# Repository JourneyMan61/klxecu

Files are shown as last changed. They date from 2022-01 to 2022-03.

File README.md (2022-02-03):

# klxecu

Speeduino based ECM for the fuel injected KLX 250 and 300. Firmware compatible with the Speeduino 0.4.4c. It has only one fuel and ignition channel, but adds a few extra features, namely:

- control of the check engine/temperature warning lights on the dashboard
- control of the secondary throttle plate in the intake (we'll abuse the open loop idle control built in to the speeduino)
- control of the bike's safety switches (tbd, might just use some logic gates. currently a DIP8 socket is available on the board for testing)
- auxiliary "self diag" pin connected to the speeduino processor

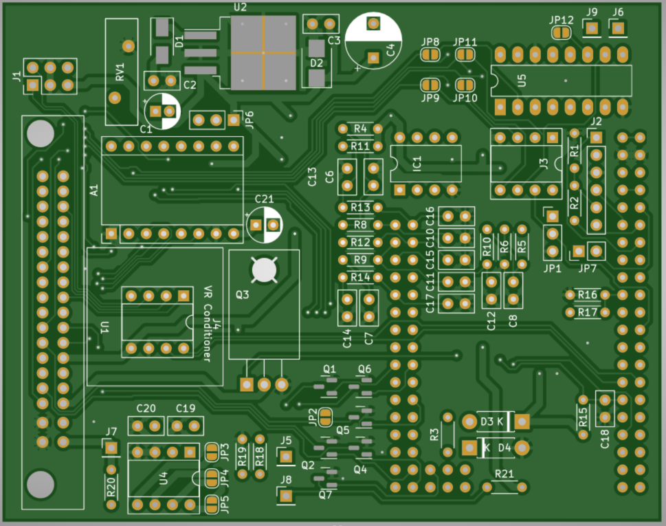
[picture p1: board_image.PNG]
klxecu v1


This project borrows from the following:

- [NO2C Speeduino - https://github.com/turboedge/SpeedyBoards](https://github.com/turboedge/SpeedyBoards) for parts of the board design
- [Speeduino Hardware - https://github.com/speeduino/Hardware](https://github.com/speeduino/Hardware) for the VR conditioner and other bits of the board design
- [Speeduino Firmware - https://github.com/noisymime/speeduino](https://github.com/noisymime/speeduino) for the ECM firmware

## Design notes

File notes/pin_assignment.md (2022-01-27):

# ECM -> Arduino Pin Assingments

| ECM Pin | Function | Schematic Alias | Arduino Pin | ATTiny Pin | Notes |
|---|---|---|---|---|---|
| 1 | Switched 12V Power | +12V | | | Input to onboard PSU |
| 2 | Vehicle Down Sensor | VDOWN | | A2 | |
| 3 | Crankshaft Position + | CKP+ | D19 | | Sensor connected to amp/conditioner, conditioner output<br>connected to D19 |
| 4 | Unconnected | | | | |
| 5 | Throttle Position Sensor | TPS | A2 | | |
| 6 | Intake air pressure sensor | MAP | A3 | | |
| 7 | Oxygen Sensor | O2S | A8 | | |
| 8 | Control Ground | GND | | | Connected to ECM internal ground |
| 9 | Crankshaft Position - | CKP- | D19 | | |
| 10 | External Communication | | | | On the original bike, this is the OEM diagnostic port.<br>It's not useful for speeduino, so it will be left unconnected |
| 11 | Fuel pump relay | FP-RELAY | D45 | | |
| 12 | Starter Lockout Switch / Clutch Switch | CLUTCH-SW | D51 | | Recommended to use for speeduino's launch control input |
| 13 | Sensor power supply | +5V | | | 5 Volts output from ECM's internal power supply |
| 14 | Subthrottle valve actuator B | SUB-B+ | | A5,A6 | B Coil positive lead for subthrottle stepper, connected to the DRV8825 |
| 15 | Subthrottle valve actuator A | SUB-A+ | | A5,A6 | A Coil positive lead for subthrottle stepper, connected to the DRV8825 |
| 16 | Fuel injector | INJ | D8 | | |
| 17 | Oxygen sensor heater | O2S-HEAT | D45 | | Microsquirt docs recommend tying this to the fuel pump.<br>Speeduino doesn't have support for O2 sensor heater control. |
| 18 | Ignition Coil | IGN | D40 | | This is normally a CDI pulse output, for v1 of the board it<br>may be a logic level output for a smart coil |
| 19 | Power supply from battery | +BATT | | | Always-on power directly from the vehicle's battery |
| 20 | Neutral Switch | NEUTRAL | | A3 | Used by the attiny to halt the main processor if we're in gear<br>and the kickstand is down |
| 21 | Check engine light | MIL | D32 | D10 | Speeduino supports programmable outputs, so we could flash the<br>lamp when engine protection is triggered or something. The speeduino will tell the<br>ATTiny something is wrong, then the ATTiny will activate the lamp. The ATTiny can also activate the lamp if the safety switch is triggered. |
| 22 | Water temperature sensor | CLT | A1 | | |
| 23 | Self diagnosis terminal | SELF-DIAG | D53? | | Will be tied to a generic digital input |
| 24 | Sensor Ground | GND | | | Ground for pressure sensors, etc. |
| 25 | Intake air temperature sensor | IAT | A0 | | |
| 26 | Speed Sensor | VSS | D20 | | Speeduino supports gear detection, maybe we can do something<br>useful with that information |
| 27 | Subthrottle sensor | SUB-TPS | | A1 | Used so the ATTiny can tell when the secondary throttle valves<br>are fully open |
| 28 | Coolant temperature warning light | TEMP-WARN | tbd | | Controlled by the speeduino's programmable outputs, can trigger<br>at a customizable temperature |
| 29 | Side stand switch | SIDE-SW | | A4 | Used by the attiny to halt the main processor if we're in gear and<br>the kickstand is down |
| 30 | Air switching valve | n/a | | | Injects air into the exhaust stream, will not be supported in v1 |
| 31 | Subthrottle valve actuator A | SUB-A- | | A5,A6 | A coil negative lead for the subthrottle stepper, connected to the DRV8825 |
| 32 | Subthrottle valve actuator B | SUB-B- | | A5,A6 | B coil negative lead for the subthrottle stepper, connected to the DRV8825 |
| 33 | Radiator Fan relay | FAN-RELAY | D47 | | |
| 34 | Engine stop switch | KILL-SW | | | This switch already provides power to the fuel injectors and fuel pump,<br>it's probably fine to leave this unconnected. or connect to the ATTiny so<br>it can shut the secondary throttles if the killswitch is enabled? |
| 35 | Ground for ECM | GND | | | |
| 36 | Ground for ECM | GND | | | 

# Auxiliary Pins
| Board Pin | Function | Schematic Alias | Arduino Pin | ATTiny Pin | Notes |
|---|---|---|---|---|---|
| J?1 | Camshaft Position Sensor + | CAM+ | D18 | | Auxiliary camshaft position sensor input, if you want to run sequential ignition... the VR conditioner has 2 channels so why not? |
| J?2 | Camshaft Position Sensor - | CAM- | D18 | | Auxiliary camshaft position sensor input, if you want to run sequential ignition... the VR conditioner has 2 channels so why not? |
| J? | Tacho output | TACH | D49 | | Tach output if needed, pads can be left blank

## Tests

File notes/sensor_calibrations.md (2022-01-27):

# Sensor Calibrations

### Throttle Position Sensor
- Input voltage spec: 5V
- Output at closed throttle: 0.58-0.62 V
- Output at WOT: 3.7-3.9V

### Crankshaft Position Sensor
- Type: Variable Reluctance
- Trigger pattern: 18-1*
- Trigger angle: ?
- Voltage peak: 3.2V

### MAP Sensor
- Pressure at 0V: ?
- Pressure at 5V: ?
- Sensor spec is 2.87-2.93V at 101.35 kPa, will need to calibrate

### O2 Sensor
- Type: Narrowband
- Rich: 0.8V and up
- Lean: 0.24V and below

### Coolant Temperature Sensor
- -20c: 18.80k +/- 2.37k
- 0c: 6.544k
- 40c: 1.136k +/- 0.095k
- 100c: 0.1553k +/- 0.0070k
- Bias resistor: TBD
- Spec voltage: 2.8-2.97V at 20c (probably won't apply for us because the bias reistor is different)

### Intake air temperature sensor
- 0c: 6k +/- 0.6k
- 80c: 0.34k +/- 0.05k
- Spec voltage at 20c is 2.375 +/- 0.125V, which works out to a theoretical resistance of 2.5k. Will need to experimentally test though.

### Subthrottle Position sensor
- Input voltage spec: 5V
- Output at closed throttle: 0.48-0.52V
- Output at WOT: 3.60-3.80V

### Speed Sensor
- Type: Hall effect
- Spec: 0-5v output
- 8 pulses per rotation

### Kickstand
- Up: Logic low (ground)
- Down: Logic high (pullup to 5V?)**

### Neutral switch
- Neutral: low
- In gear: hign (pullup to 5V?)**

### Clutch Switch
- Pulled in: low
- let out: high (pulled up? who knows. let's see)

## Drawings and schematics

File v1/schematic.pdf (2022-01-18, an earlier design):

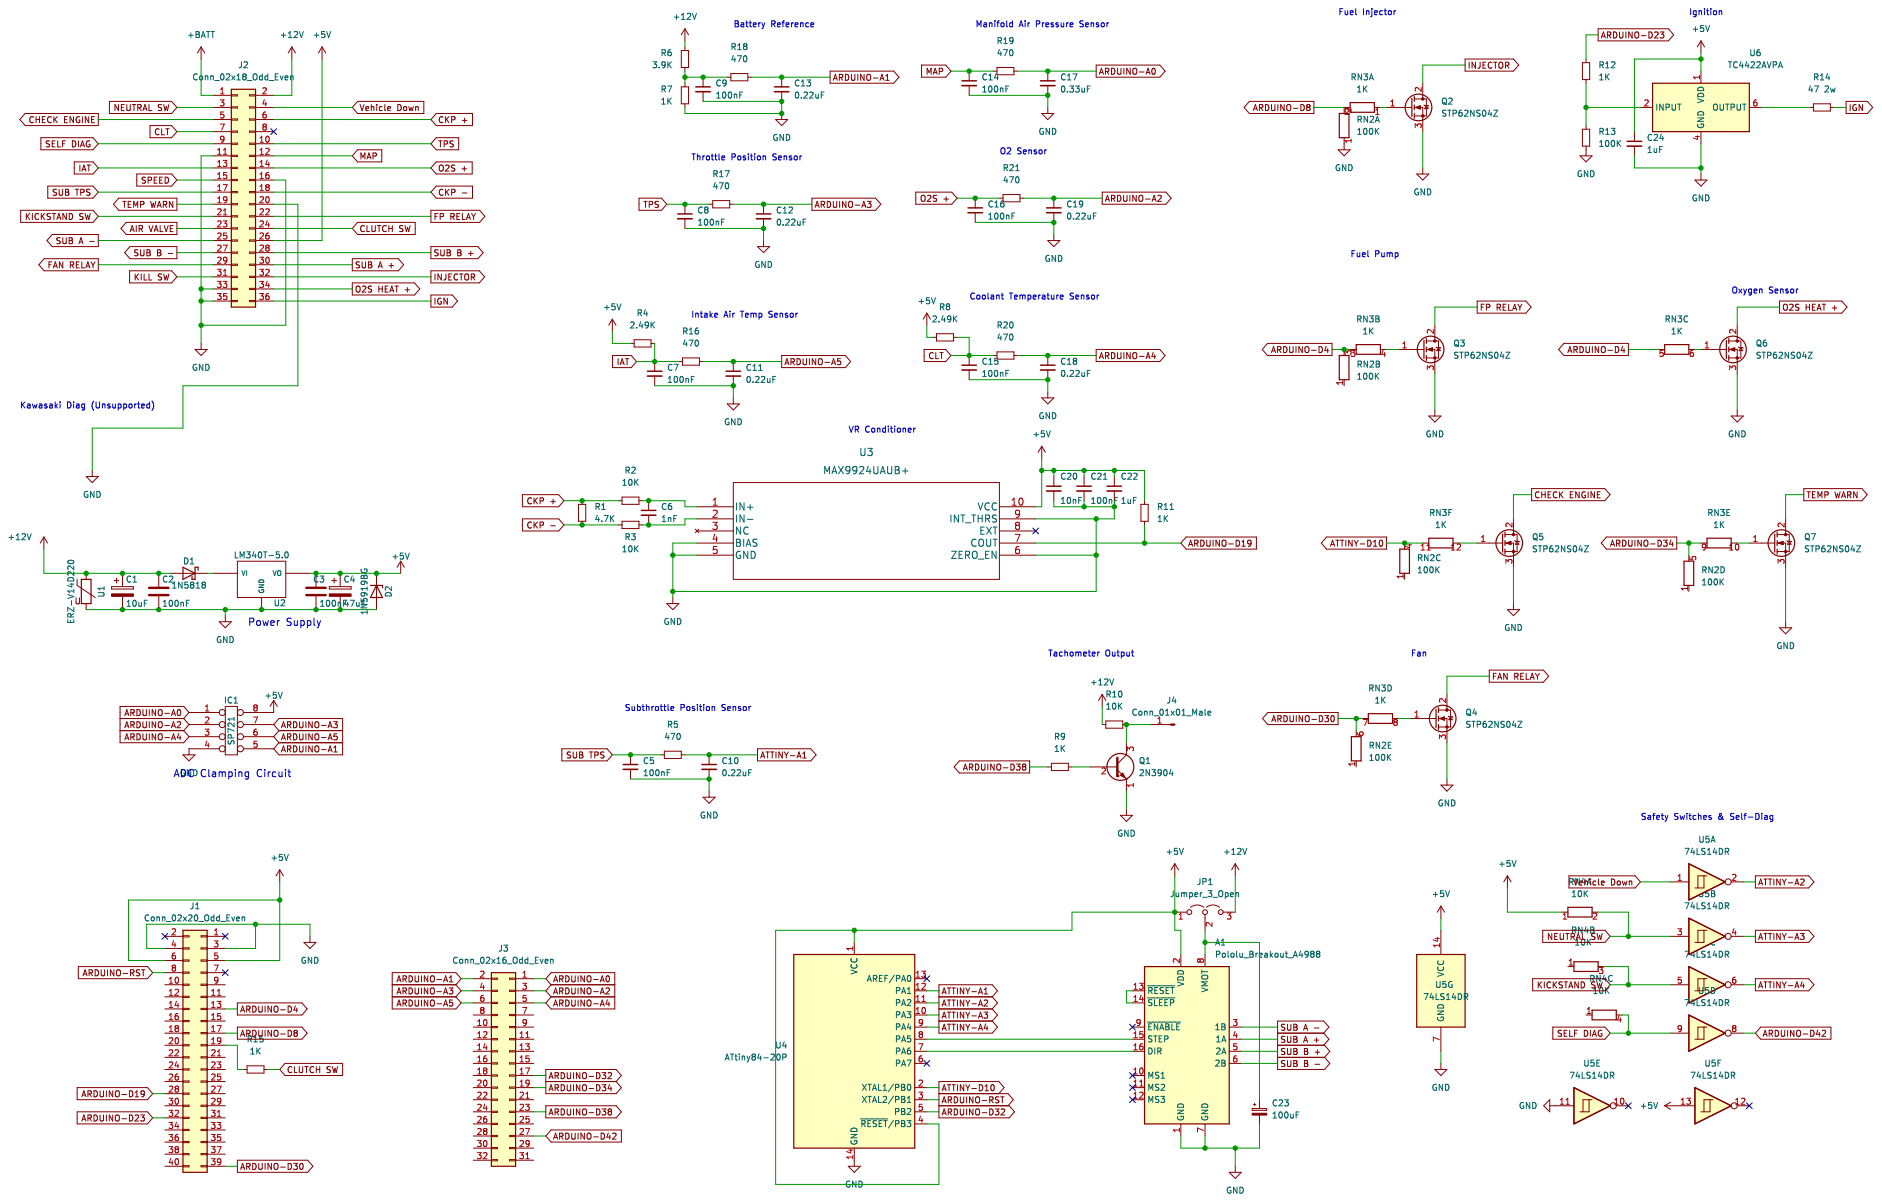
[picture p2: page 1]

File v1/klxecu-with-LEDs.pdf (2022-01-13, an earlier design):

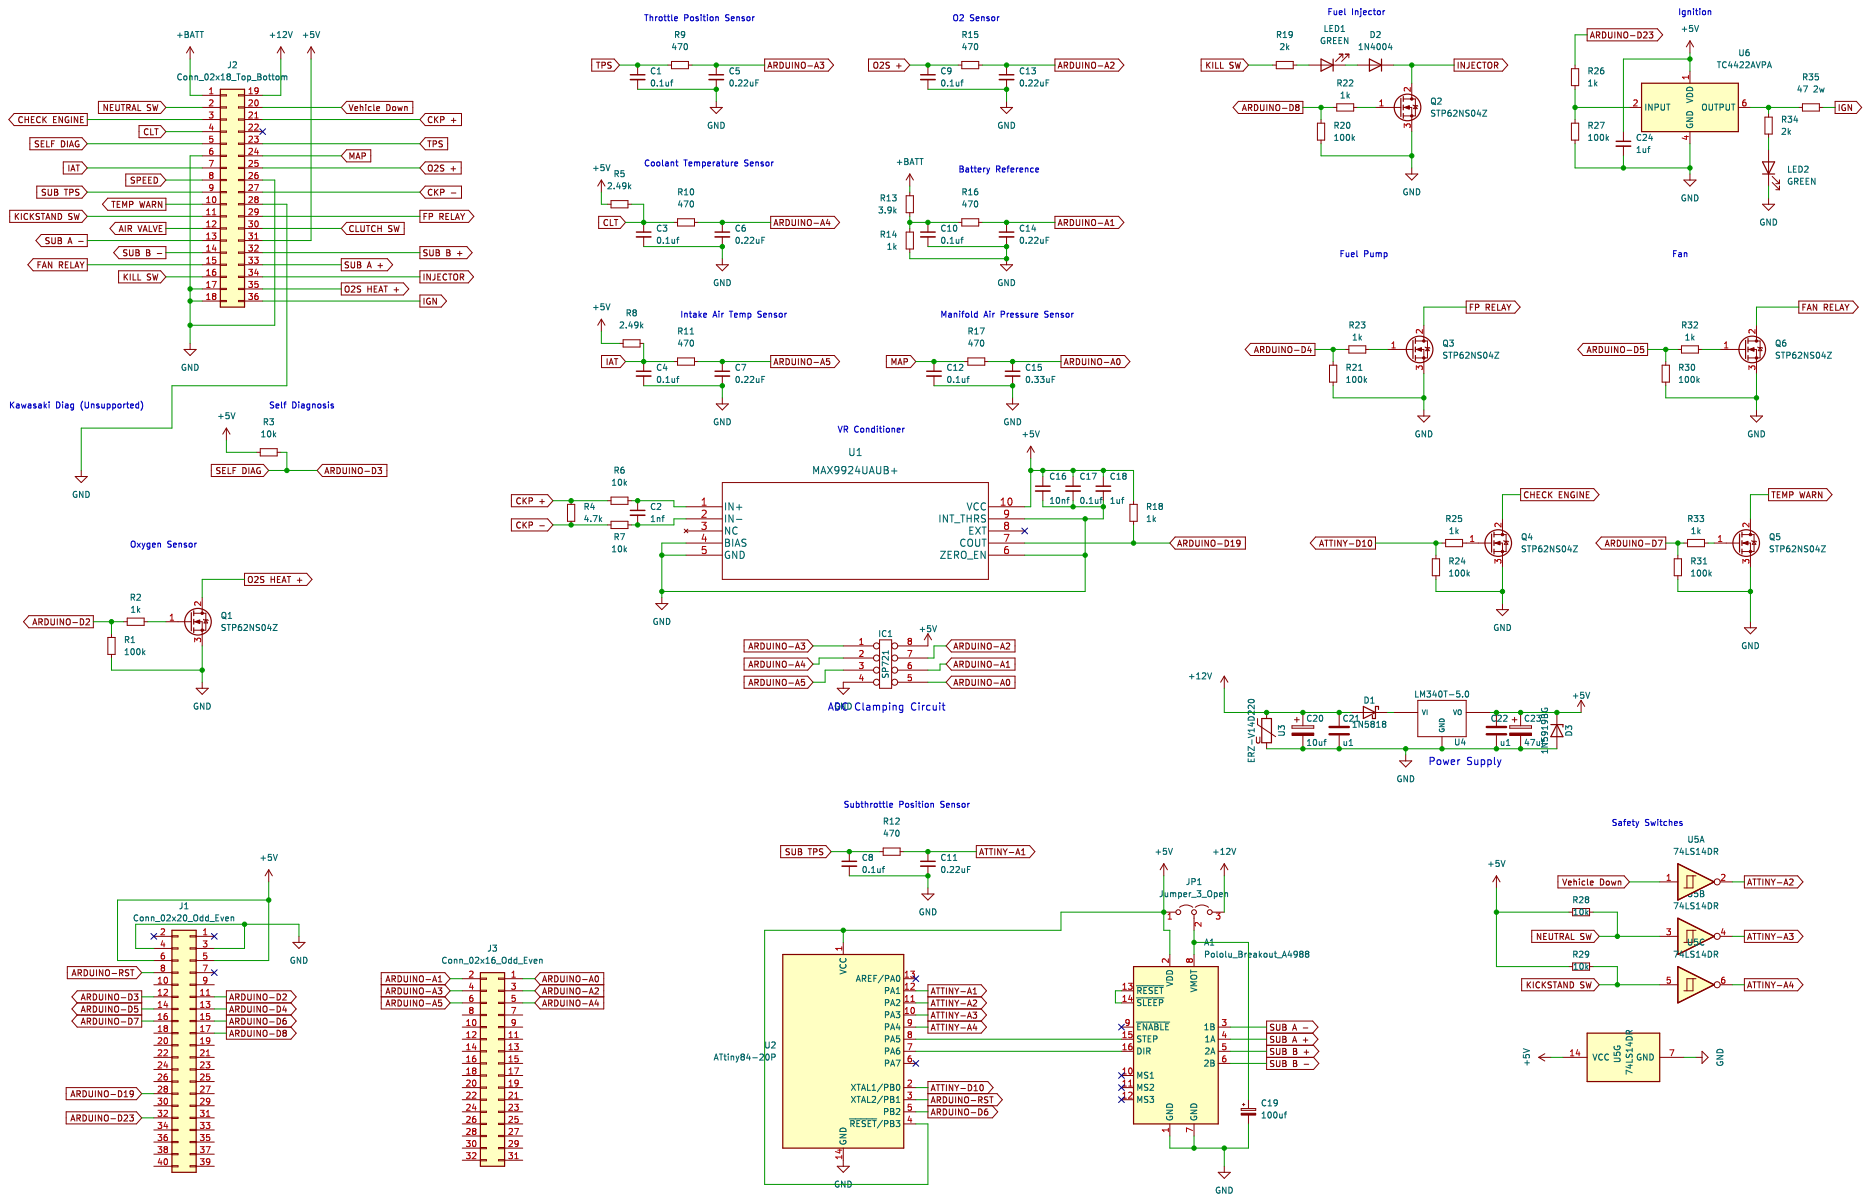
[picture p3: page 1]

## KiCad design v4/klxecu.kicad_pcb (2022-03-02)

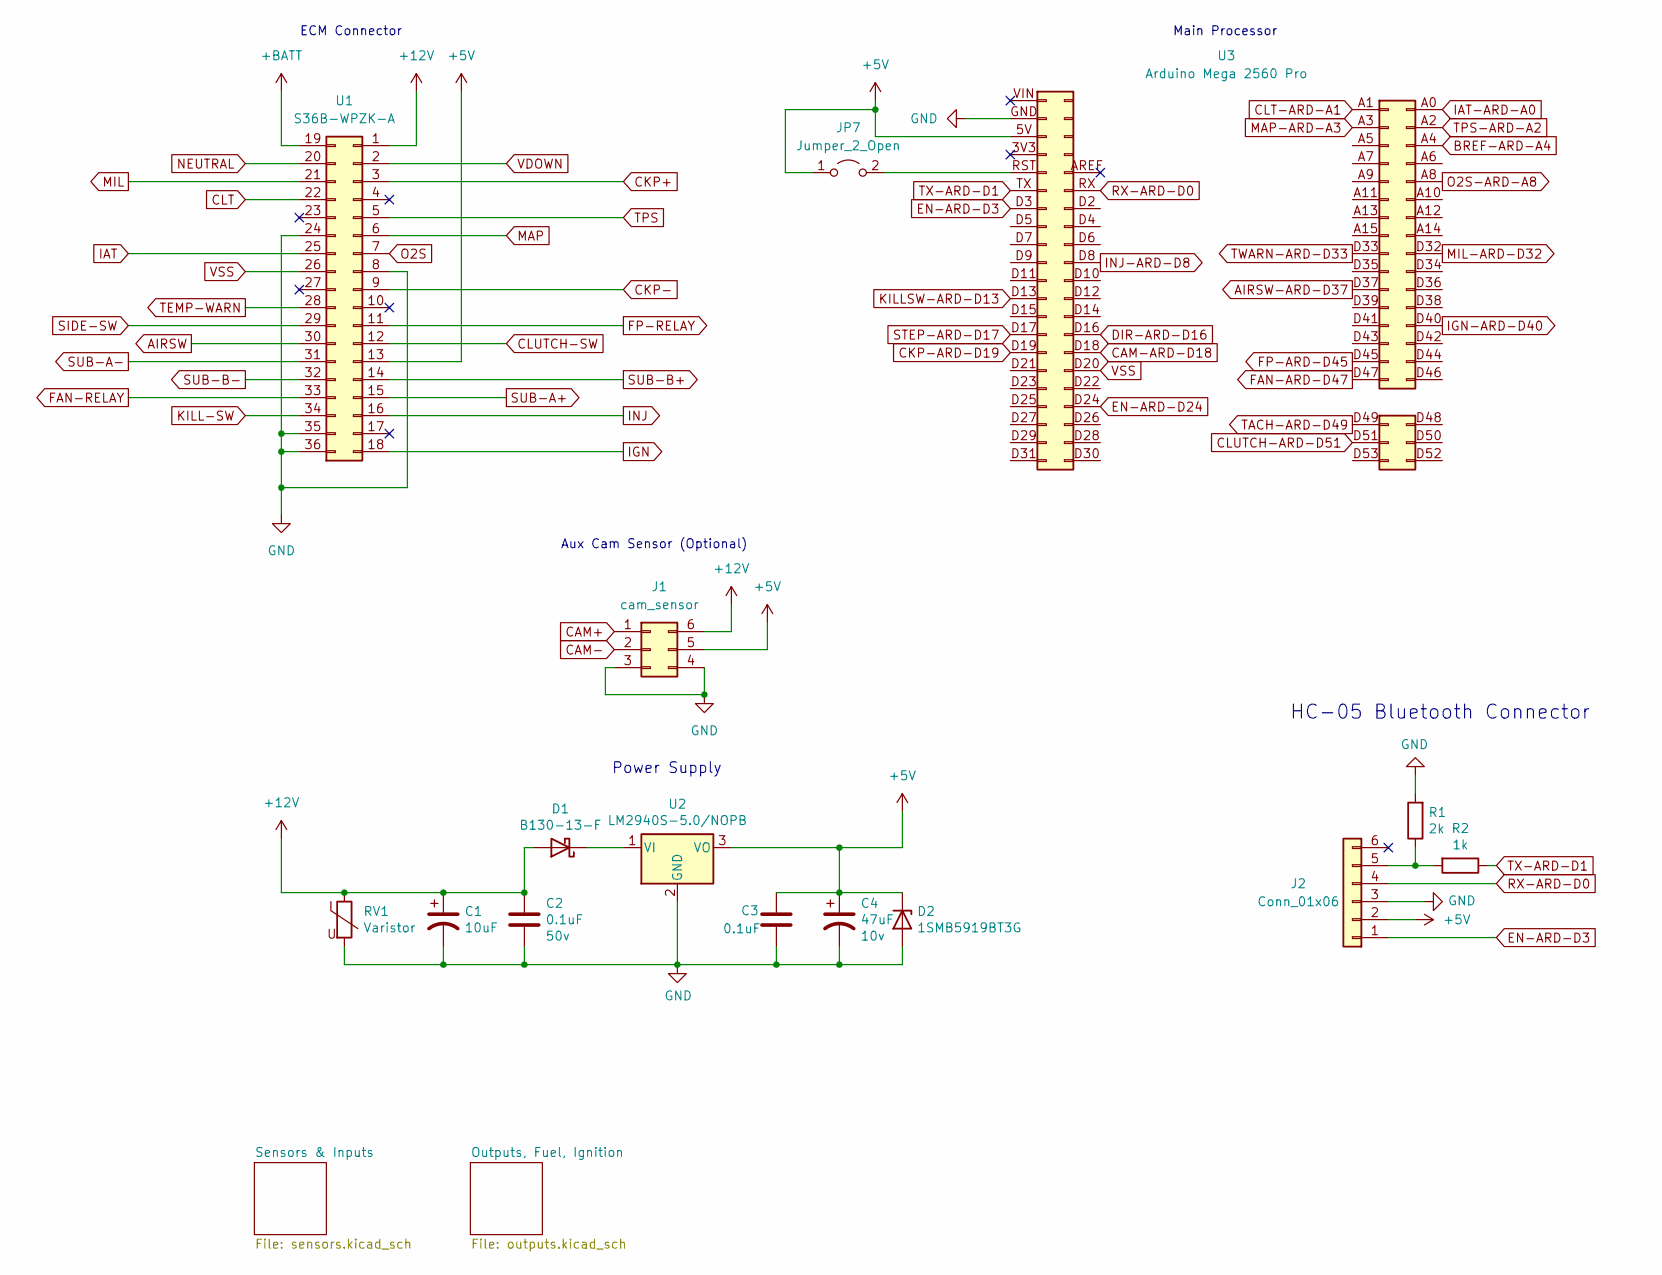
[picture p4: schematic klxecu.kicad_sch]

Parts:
C1: 10uF; CP_Radial_D5.0mm_P2.00mm; Voltage 35v; Manufacturer_Part_Number T491D106K050AT; Digikey Part Number 399-8361-1-ND
C2: 0.1uF; C_Disc_D5.0mm_W2.5mm_P2.50mm; Voltage 50v; Manufacturer_Part_Number CC0805KRX7R9BB104; Digikey Part Number 311-1140-1-ND
C3: 0.1uF; C_Disc_D5.0mm_W2.5mm_P2.50mm; Manufacturer_Part_Number CC0805KRX7R9BB104; Digikey Part Number 311-1140-1-ND
C4: 47uF; CP_Radial_D8.0mm_P5.00mm; Voltage 10v; Manufacturer_Part_Number TAJB476K006RNJ; Digikey Part Number 478-1692-1-ND
D1: B130-13-F; D_SMA; Manufacturer_Part_Number B130-13-F; Digikey Part Number B130-FDICT-ND
D2: 1SMB5919BT3G; D_SMB; Manufacturer_Part_Number 1SMB5919BT3G; Digikey Part Number 1SMB5919BT3GOSCT-ND
J1: cam_sensor; PinHeader_2x03_P2.54mm_Vertical
J2: Conn_01x06; PinHeader_1x06_P2.54mm_Vertical
JP7: Jumper_2_Open; PinHeader_1x02_P2.54mm_Vertical
R1: 2k; R_Axial_DIN0204_L3.6mm_D1.6mm_P5.08mm_Horizontal; Manufacturer_Part_Number RC0805FR-072KL; Digikey Part Number 311-2.00KCRCT-ND
R2: 1k; R_Axial_DIN0204_L3.6mm_D1.6mm_P5.08mm_Horizontal; Manufacturer_Part_Number RC0805FR-071KL; Digikey Part Number 311-1.00KCRCT-ND
RV1: Varistor; RV_Disc_D15.5mm_W4.7mm_P7.5mm; Manufacturer_Part_Number MOV-14D220K; Digikey Part Number MOV-14D220K-ND
U1: S36B-WPZK-A
U2: LM2940S-5.0/NOPB; TO-263-3_TabPin2; Manufacturer_Part_Number LM2940S-5.0/NOPB; Digikey Part Number LM2940S-5.0/NOPB-ND
U3: Arduino Mega 2560 Pro; mega_2560_pro

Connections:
+5V: C3.1, C4.1, D2.1 (K), J1.5, J2.2, JP7.1 (A), U1.13, U2.3 (VO), U3.5V; also elsewhere on the board
+12V: C1.1, C2.1, D1.2 (A), J1.6, RV1.1, U1.1; also elsewhere on the board
+BATT: U1.19
AIRSW: U1.30; also elsewhere on the board
AIRSW-ARD-D37: U3.D37; also elsewhere on the board
BREF-ARD-A4: U3.A4; also elsewhere on the board
CAM+: J1.1; also elsewhere on the board
CAM-: J1.2; also elsewhere on the board
CAM-ARD-D18: U3.D18; also elsewhere on the board
CKP+: U1.3; also elsewhere on the board
CKP-: U1.9; also elsewhere on the board
CKP-ARD-D19: U3.D19; also elsewhere on the board
CLT: U1.22; also elsewhere on the board
CLT-ARD-A1: U3.A1; also elsewhere on the board
CLUTCH-ARD-D51: U3.D51; also elsewhere on the board
CLUTCH-SW: U1.12; also elsewhere on the board
DIR-ARD-D16: U3.D16; also elsewhere on the board
EN-ARD-D3: J2.1, U3.D3
EN-ARD-D24: U3.D24; also elsewhere on the board
FAN-ARD-D47: U3.D47; also elsewhere on the board
FAN-RELAY: U1.33; also elsewhere on the board
FP-ARD-D45: U3.D45; also elsewhere on the board
FP-RELAY: U1.11; also elsewhere on the board
GND: C1.2, C2.2, C3.2, C4.2, D2.2 (A), J1.3, J1.4, J2.3, R1.2, RV1.2, U1.8, U1.24, U1.35, U1.36, U2.2 (GND), U3.GND; also elsewhere on the board
IAT: U1.25; also elsewhere on the board
IAT-ARD-A0: U3.A0; also elsewhere on the board
IGN: U1.18; also elsewhere on the board
IGN-ARD-D40: U3.D40; also elsewhere on the board
INJ: U1.16; also elsewhere on the board
INJ-ARD-D8: U3.D8; also elsewhere on the board
KILL-SW: U1.34; also elsewhere on the board
KILLSW-ARD-D13: U3.D13; also elsewhere on the board
MAP: U1.6; also elsewhere on the board
MAP-ARD-A3: U3.A3; also elsewhere on the board
MIL: U1.21; also elsewhere on the board
MIL-ARD-D32: U3.D32; also elsewhere on the board
NEUTRAL: U1.20; also elsewhere on the board
unnamed: D1.1 (K), U2.1 (VI)
unnamed: J2.5, R1.1, R2.2
unnamed: JP7.2 (B), U3.RST
O2S: U1.7; also elsewhere on the board
O2S-ARD-A8: U3.A8; also elsewhere on the board
RX-ARD-D0: J2.4, U3.RX
SIDE-SW: U1.29; also elsewhere on the board
STEP-ARD-D17: U3.D17; also elsewhere on the board
SUB-A+: U1.15; also elsewhere on the board
SUB-A-: U1.31; also elsewhere on the board
SUB-B+: U1.14; also elsewhere on the board
SUB-B-: U1.32; also elsewhere on the board
TACH-ARD-D49: U3.D49; also elsewhere on the board
TEMP-WARN: U1.28; also elsewhere on the board
TPS: U1.5; also elsewhere on the board
TPS-ARD-A2: U3.A2; also elsewhere on the board
TWARN-ARD-D33: U3.D33; also elsewhere on the board
TX-ARD-D1: R2.1, U3.TX
VDOWN: U1.2; also elsewhere on the board
VSS: U1.26, U3.D20; also elsewhere on the board

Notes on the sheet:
Aux Cam Sensor (Optional)
HC-05 Bluetooth Connector
ECM Connector
Main Processor
Power Supply

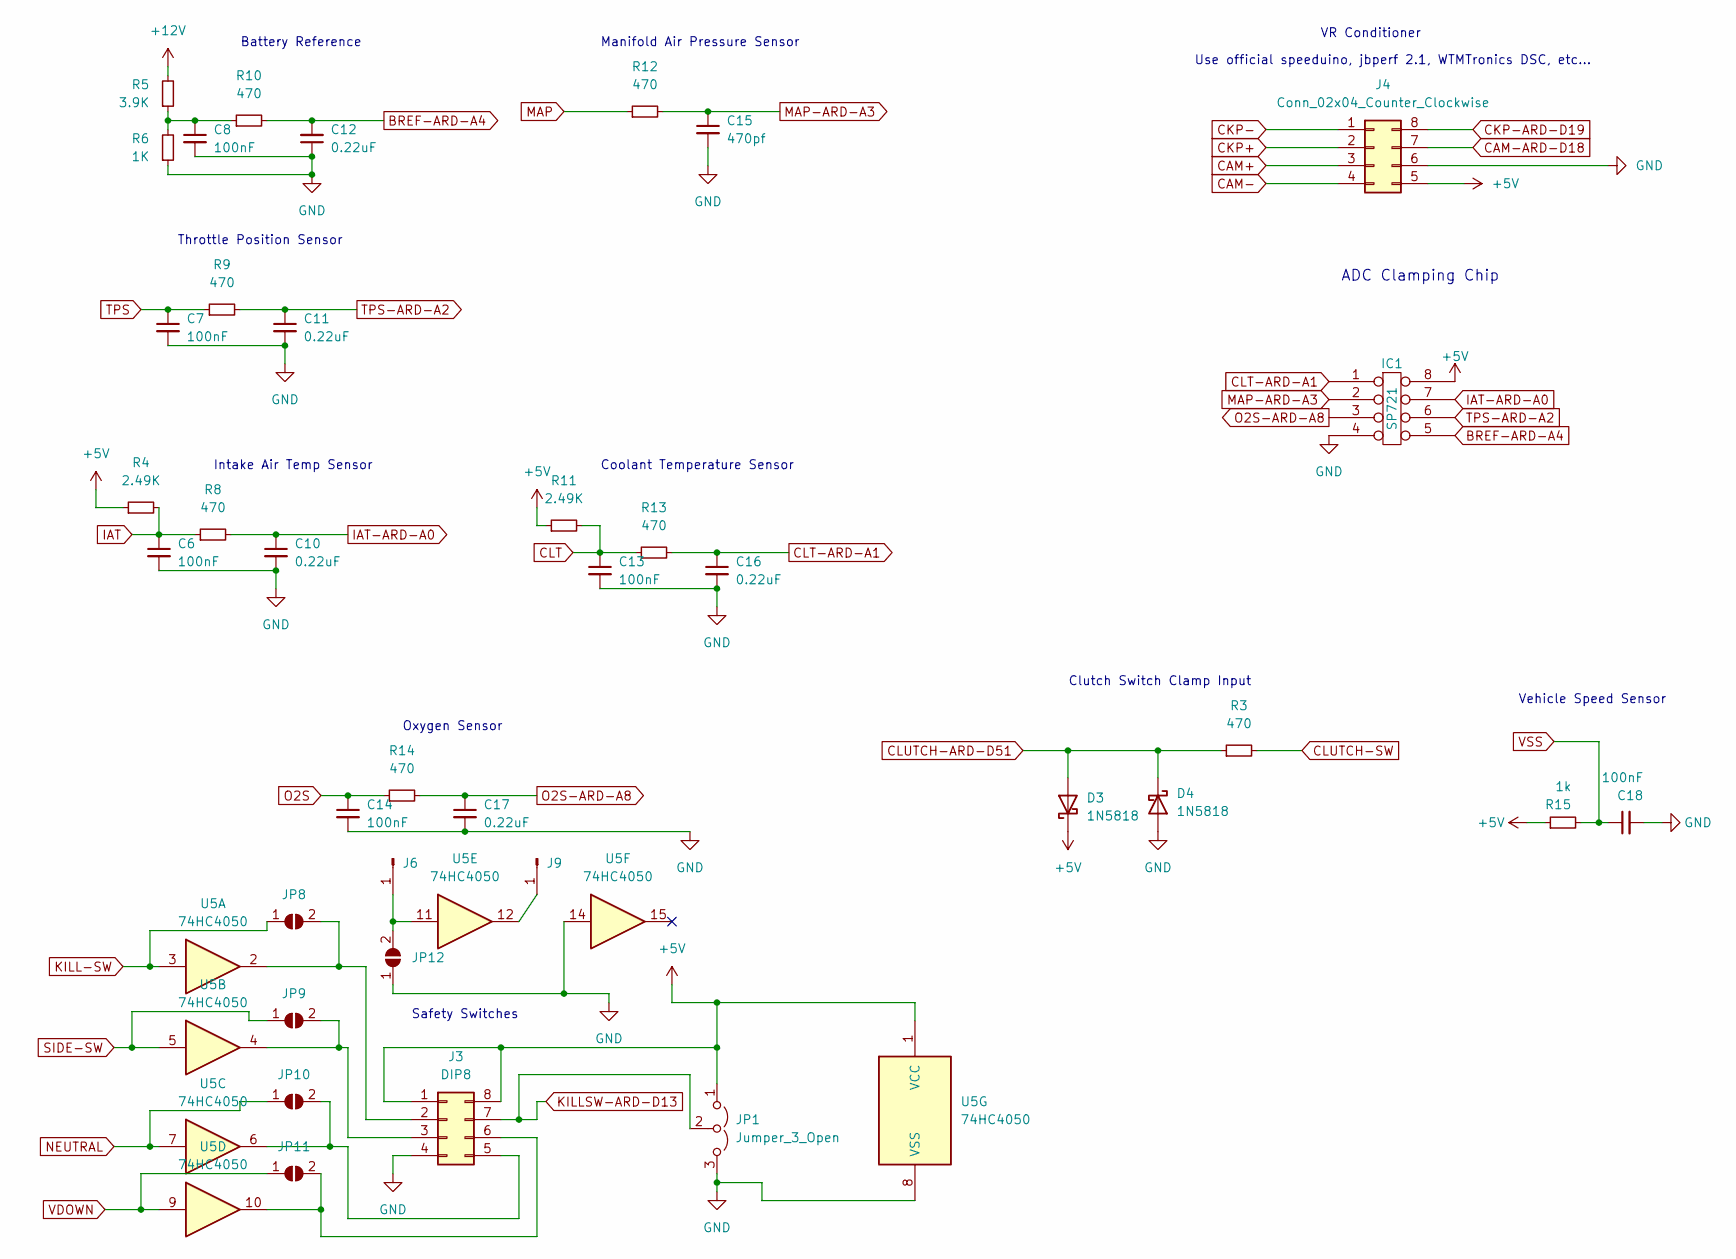
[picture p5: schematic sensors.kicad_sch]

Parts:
C6, C7, C8, C13, C14: 100nF; C_Disc_D5.0mm_W2.5mm_P2.50mm
C10, C11, C12, C16, C17: 0.22uF; C_Disc_D5.0mm_W2.5mm_P2.50mm
C15: 470pf; C_Disc_D5.0mm_W2.5mm_P2.50mm
C18: 100nF; C_Disc_D5.0mm_W2.5mm_P2.50mm; Manufacturer_Part_Number CC0805KRX7R9BB104; Digikey 311-1140-1-ND
D3, D4: 1N5818; D_DO-41_SOD81_P7.62mm_Horizontal
IC1: SP721; DIP-8_W7.62mm
J3: DIP8; DIP-8_W7.62mm_Socket
J4: Conn_02x04_Counter_Clockwise; vr_conditioner
J6, J9: Conn_01x01_Male; PinHeader_1x01_P2.54mm_Vertical
JP1: Jumper_3_Open; PinHeader_1x03_P2.54mm_Vertical
JP8, JP9, JP10, JP11, JP12: SolderJumper_2_Open; SolderJumper-2_P1.3mm_Open_RoundedPad1.0x1.5mm
R3, R8, R9, R10, R12, R13, R14: 470; R_Axial_DIN0204_L3.6mm_D1.6mm_P5.08mm_Horizontal
R4, R11: 2.49K; R_Axial_DIN0204_L3.6mm_D1.6mm_P5.08mm_Horizontal
R5: 3.9K; R_Axial_DIN0204_L3.6mm_D1.6mm_P5.08mm_Horizontal
R6: 1K; R_Axial_DIN0204_L3.6mm_D1.6mm_P5.08mm_Horizontal
R15: 1k; R_Axial_DIN0204_L3.6mm_D1.6mm_P5.08mm_Horizontal
U5: 74HC4050; DIP-16_W7.62mm_LongPads

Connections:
+5V: D3.1 (K), IC1.8, J3.1, J3.8, J4.5, JP1.1 (A), R4.1, R11.1, R15.1, U5.1 (VCC); also elsewhere on the board
+12V: R5.2; also elsewhere on the board
BREF-ARD-A4: C12.2, IC1.5, R10.2; also elsewhere on the board
CAM+: J4.3; also elsewhere on the board
CAM-: J4.4; also elsewhere on the board
CAM-ARD-D18: J4.7; also elsewhere on the board
CKP+: J4.2; also elsewhere on the board
CKP-: J4.1; also elsewhere on the board
CKP-ARD-D19: J4.8; also elsewhere on the board
CLT: C13.1, R11.2, R13.1; also elsewhere on the board
CLT-ARD-A1: C16.1, IC1.1, R13.2; also elsewhere on the board
CLUTCH-ARD-D51: D3.2 (A), D4.1 (K), R3.1; also elsewhere on the board
CLUTCH-SW: R3.2; also elsewhere on the board
GND: C6.2, C7.2, C8.2, C10.2, C11.2, C12.1, C13.2, C14.2, C15.2, C16.2, C17.2, C18.2, D4.2 (A), IC1.4, J3.4, J4.6, JP1.3 (B), JP12.1 (A), R6.1, U5.8 (VSS), U5.14; also elsewhere on the board
IAT: C6.1, R4.2, R8.1; also elsewhere on the board
IAT-ARD-A0: C10.1, IC1.7, R8.2; also elsewhere on the board
KILL-SW: JP8.1 (A), U5.3; also elsewhere on the board
KILLSW-ARD-D13: J3.7, JP1.2 (C); also elsewhere on the board
MAP: R12.1; also elsewhere on the board
MAP-ARD-A3: C15.1, IC1.2, R12.2; also elsewhere on the board
NEUTRAL: JP10.1 (A), U5.7; also elsewhere on the board
unnamed: C8.1, R5.1, R6.2, R10.1
unnamed: J3.2, JP8.2 (B), U5.2
unnamed: J3.3, JP9.2 (B), U5.4
unnamed: J3.5, JP10.2 (B), U5.6
unnamed: J3.6, JP11.2 (B), U5.10
unnamed: J6.1, JP12.2 (B), U5.11
unnamed: J9.1, U5.12
O2S: C14.1, R14.1; also elsewhere on the board
O2S-ARD-A8: C17.1, IC1.3, R14.2; also elsewhere on the board
SIDE-SW: JP9.1 (A), U5.5; also elsewhere on the board
TPS: C7.1, R9.1; also elsewhere on the board
TPS-ARD-A2: C11.1, IC1.6, R9.2; also elsewhere on the board
VDOWN: JP11.1 (A), U5.9; also elsewhere on the board
VSS: C18.1, R15.2; also elsewhere on the board

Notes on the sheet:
Throttle Position Sensor
Coolant Temperature Sensor
Clutch Switch Clamp Input
Intake Air Temp Sensor
Manifold Air Pressure Sensor
Safety Switches
VR Conditioner
Vehicle Speed Sensor
Battery Reference
Use official speeduino, jbperf 2.1, WTMTronics DSC, etc...
ADC Clamping Chip
Oxygen Sensor

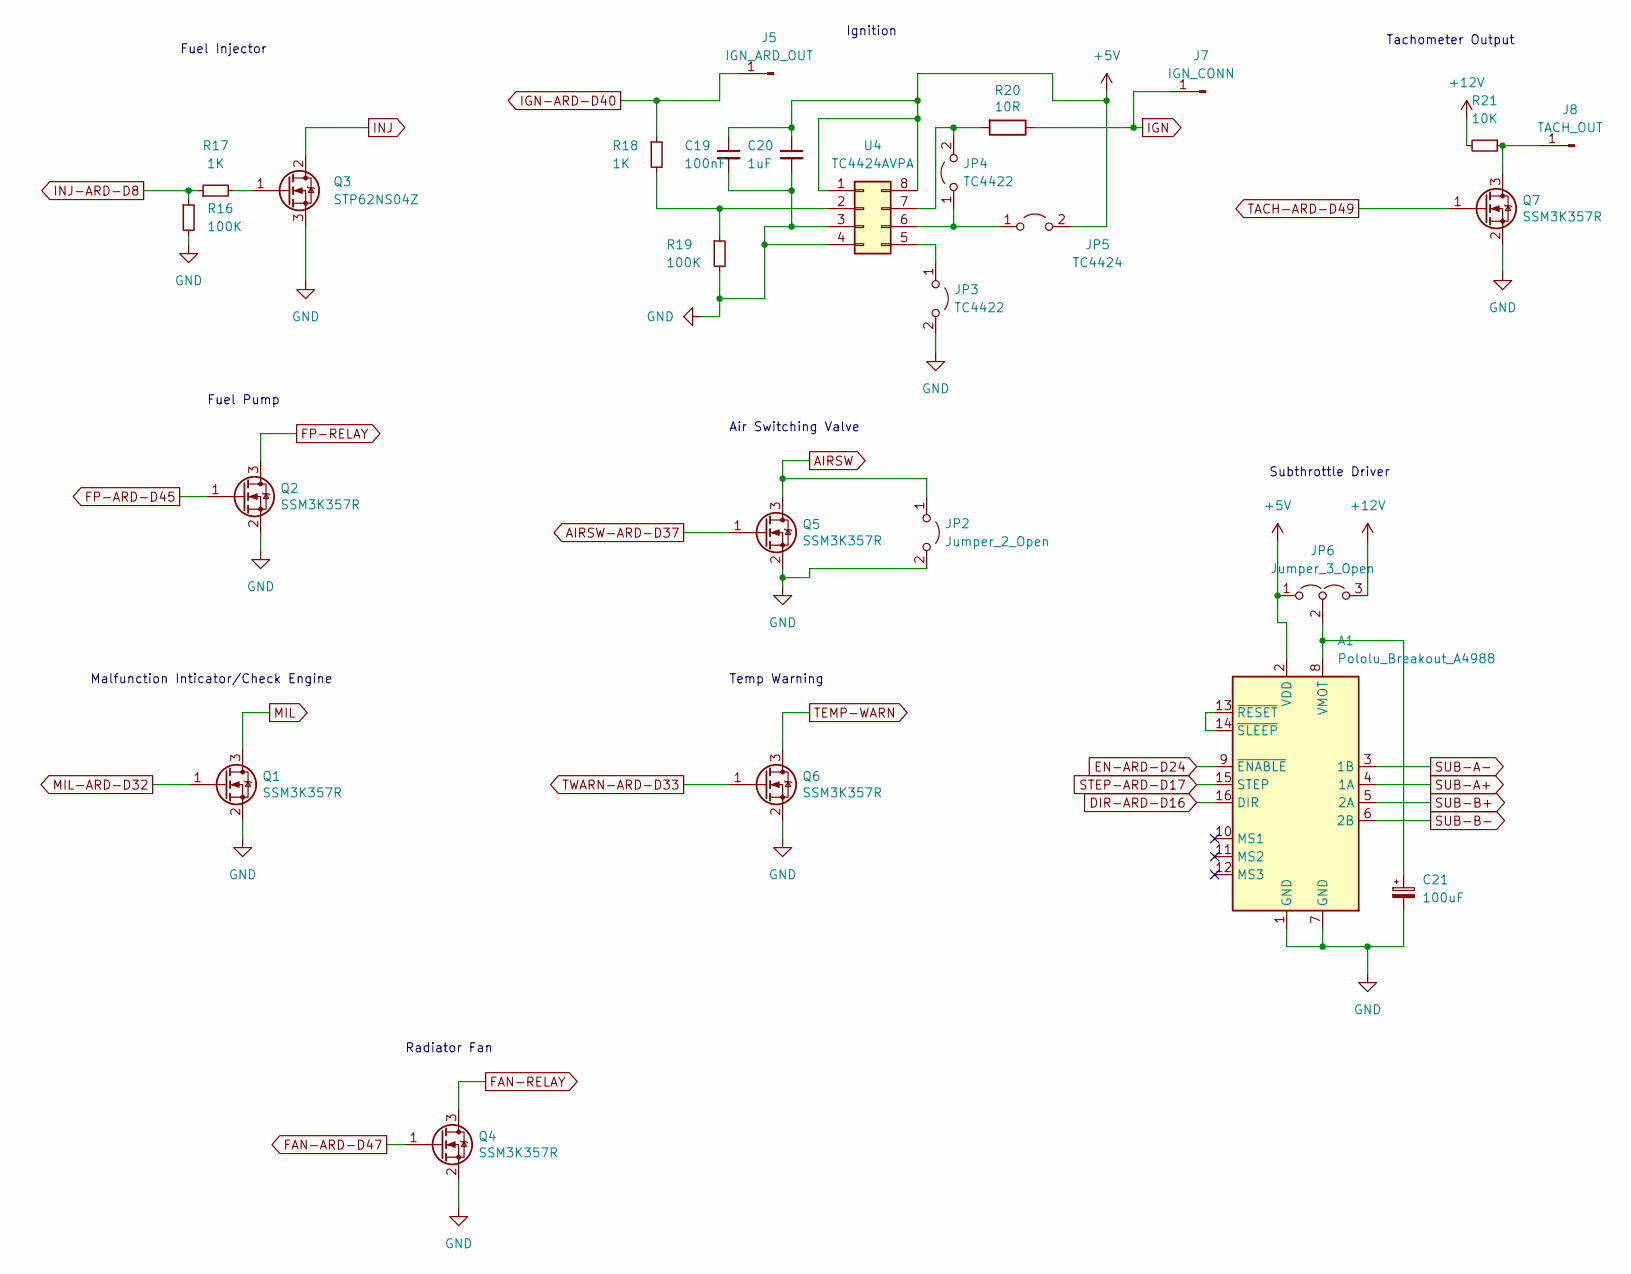
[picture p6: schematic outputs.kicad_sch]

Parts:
A1: Pololu_Breakout_A4988; Pololu_Breakout-16_15.2x20.3mm
C19: 100nF; C_Disc_D5.0mm_W2.5mm_P2.50mm
C20: 1uF; C_Disc_D5.0mm_W2.5mm_P2.50mm
C21: 100uF; CP_Radial_D5.0mm_P2.50mm
J5: IGN_ARD_OUT; PinHeader_1x01_P2.54mm_Vertical
J7: IGN_CONN; PinHeader_1x01_P2.54mm_Vertical
J8: TACH_OUT; PinHeader_1x01_P2.54mm_Vertical
JP2: Jumper_2_Open; SolderJumper-2_P1.3mm_Open_RoundedPad1.0x1.5mm
JP3, JP4: TC4422; SolderJumper-2_P1.3mm_Open_RoundedPad1.0x1.5mm
JP5: TC4424; SolderJumper-2_P1.3mm_Open_RoundedPad1.0x1.5mm
JP6: Jumper_3_Open; PinHeader_1x03_P2.54mm_Vertical
Q1, Q2, Q4, Q5, Q6, Q7: SSM3K357R; SOT-23; Manufacturer_Part_Number SSM3K357R; Digikey Part Number SSM3K357RLFCT-ND
Q3: STP62NS04Z; TO-220-3_Horizontal_TabDown
R16, R19: 100K; R_Axial_DIN0204_L3.6mm_D1.6mm_P5.08mm_Horizontal
R17, R18: 1K; R_Axial_DIN0204_L3.6mm_D1.6mm_P5.08mm_Horizontal
R20: 10R; R_Axial_DIN0204_L3.6mm_D1.6mm_P5.08mm_Horizontal; Manufacturer_Part_Number RC0805FR-0710RL; Digikey Part Number 311-10.0CRCT-ND
R21: 10K; R_Axial_DIN0204_L3.6mm_D1.6mm_P5.08mm_Horizontal
U4: TC4424AVPA; DIP-8_W7.62mm_Socket

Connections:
+5V: A1.2 (VDD), C19.1, C20.1, JP5.2 (B), JP6.1 (A), U4.1, U4.8; also elsewhere on the board
+12V: JP6.3 (B), R21.2; also elsewhere on the board
AIRSW: JP2.1 (A), Q5.3 (D); also elsewhere on the board
AIRSW-ARD-D37: Q5.1 (G); also elsewhere on the board
DIR-ARD-D16: A1.16 (DIR); also elsewhere on the board
EN-ARD-D24: A1.9 (~ENABLE); also elsewhere on the board
FAN-ARD-D47: Q4.1 (G); also elsewhere on the board
FAN-RELAY: Q4.3 (D); also elsewhere on the board
FP-ARD-D45: Q2.1 (G); also elsewhere on the board
FP-RELAY: Q2.3 (D); also elsewhere on the board
GND: A1.1 (GND), A1.7 (GND), C19.2, C20.2, C21.2, JP2.2 (B), JP3.2 (B), Q1.2 (S), Q2.2 (S), Q3.3 (S), Q4.2 (S), Q5.2 (S), Q6.2 (S), Q7.2 (S), R16.2, R19.2, U4.3, U4.4; also elsewhere on the board
IGN: J7.1, R20.1; also elsewhere on the board
IGN-ARD-D40: J5.1, R18.1; also elsewhere on the board
INJ: Q3.2 (D); also elsewhere on the board
INJ-ARD-D8: R16.1, R17.1; also elsewhere on the board
MIL: Q1.3 (D); also elsewhere on the board
MIL-ARD-D32: Q1.1 (G); also elsewhere on the board
unnamed: A1.8 (VMOT), C21.1, JP6.2 (C)
unnamed: A1.13 (~RESET), A1.14 (~SLEEP)
unnamed: J8.1, Q7.3 (D), R21.1
unnamed: JP3.1 (A), U4.5
unnamed: JP4.1 (A), JP5.1 (A), U4.6
unnamed: JP4.2 (B), R20.2, U4.7
unnamed: Q3.1 (G), R17.2
unnamed: R18.2, R19.1, U4.2
STEP-ARD-D17: A1.15 (STEP); also elsewhere on the board
SUB-A+: A1.4 (1A); also elsewhere on the board
SUB-A-: A1.3 (1B); also elsewhere on the board
SUB-B+: A1.5 (2A); also elsewhere on the board
SUB-B-: A1.6 (2B); also elsewhere on the board
TACH-ARD-D49: Q7.1 (G); also elsewhere on the board
TEMP-WARN: Q6.3 (D); also elsewhere on the board
TWARN-ARD-D33: Q6.1 (G); also elsewhere on the board

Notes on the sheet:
Radiator Fan
Fuel Pump
Ignition
Fuel Injector
Malfunction Inticator/Check Engine
Tachometer Output
Subthrottle Driver
Air Switching Valve
Temp Warning

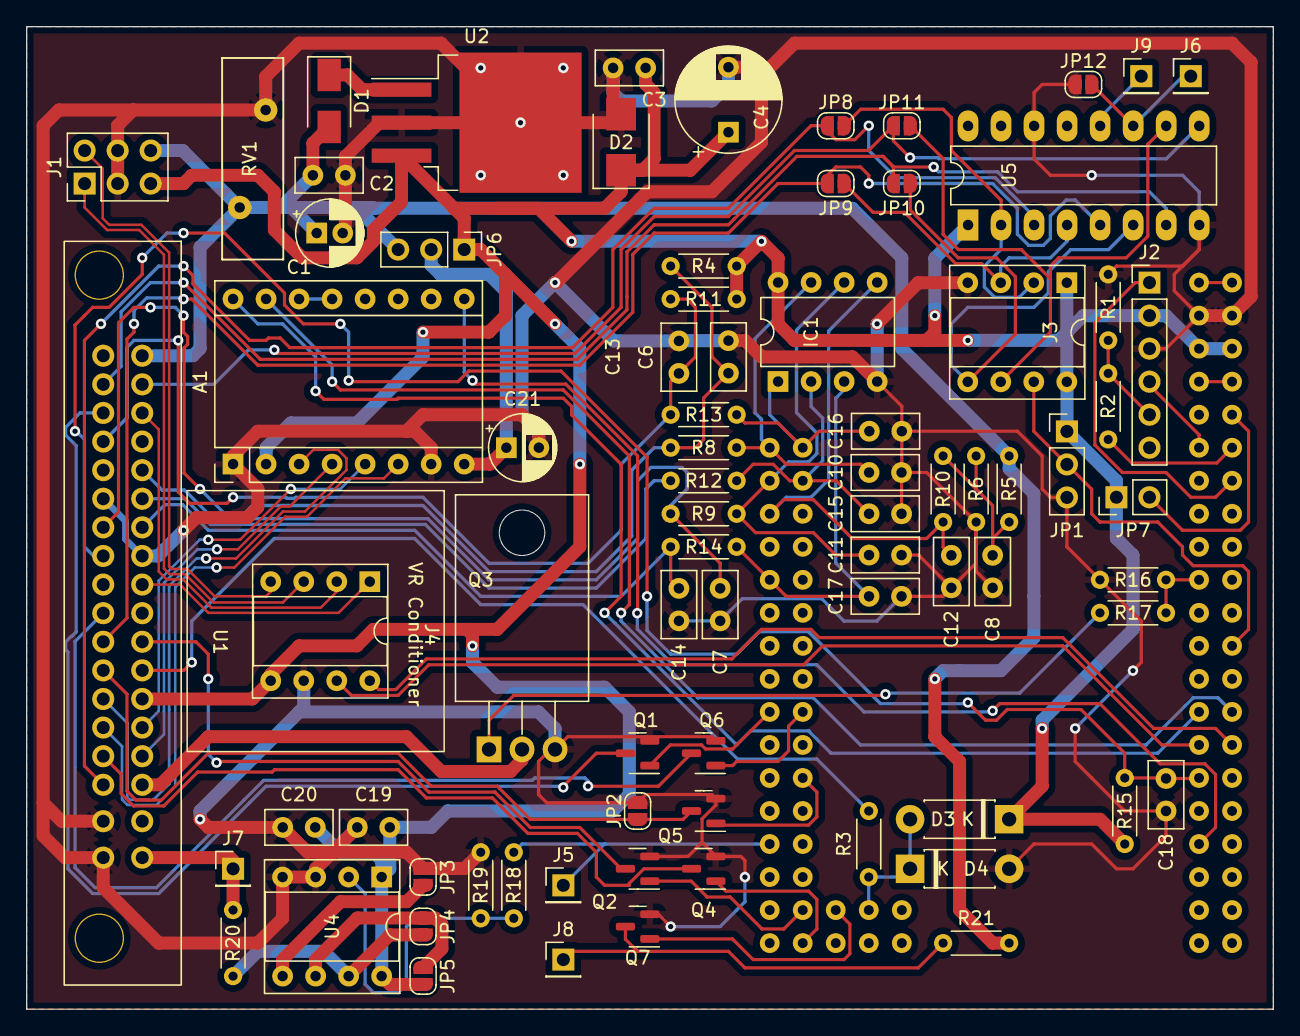
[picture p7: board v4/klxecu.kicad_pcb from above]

Board: 2 copper layers, 95.9 x 75.6 mm, 79 parts (1 on the bottom side), 71 nets.

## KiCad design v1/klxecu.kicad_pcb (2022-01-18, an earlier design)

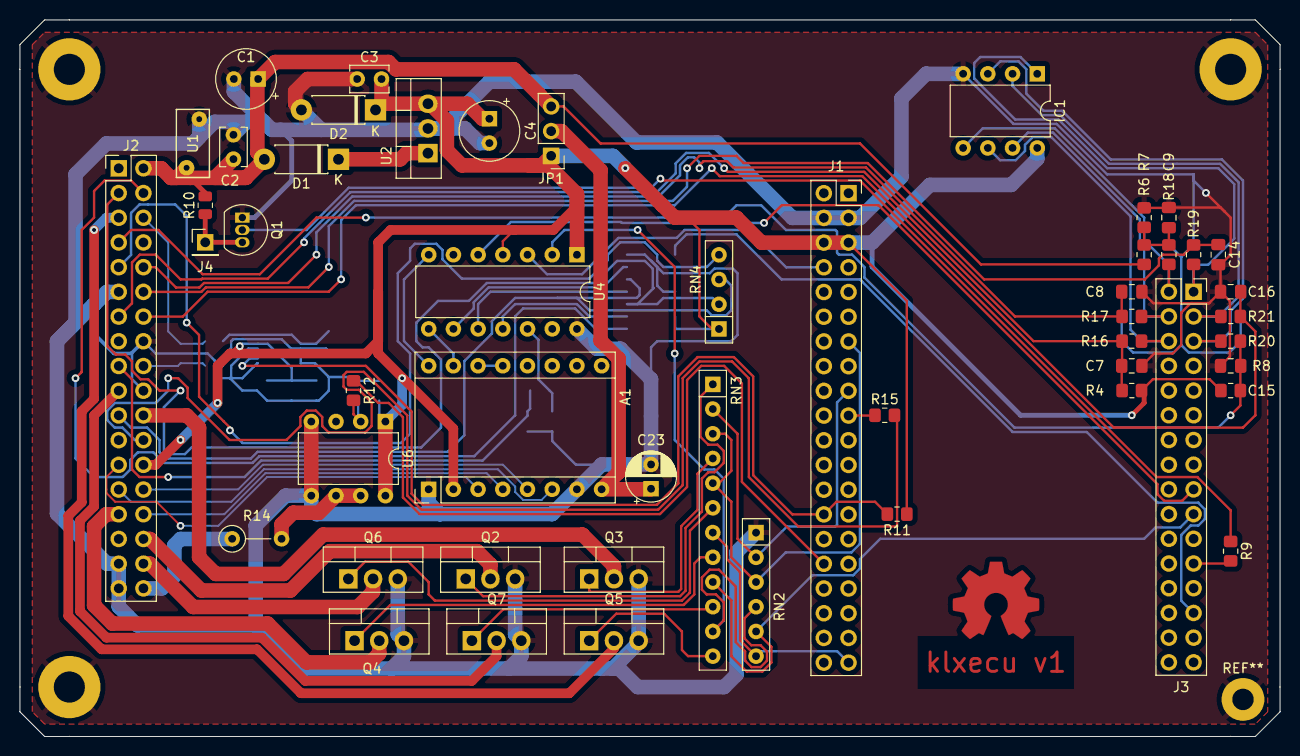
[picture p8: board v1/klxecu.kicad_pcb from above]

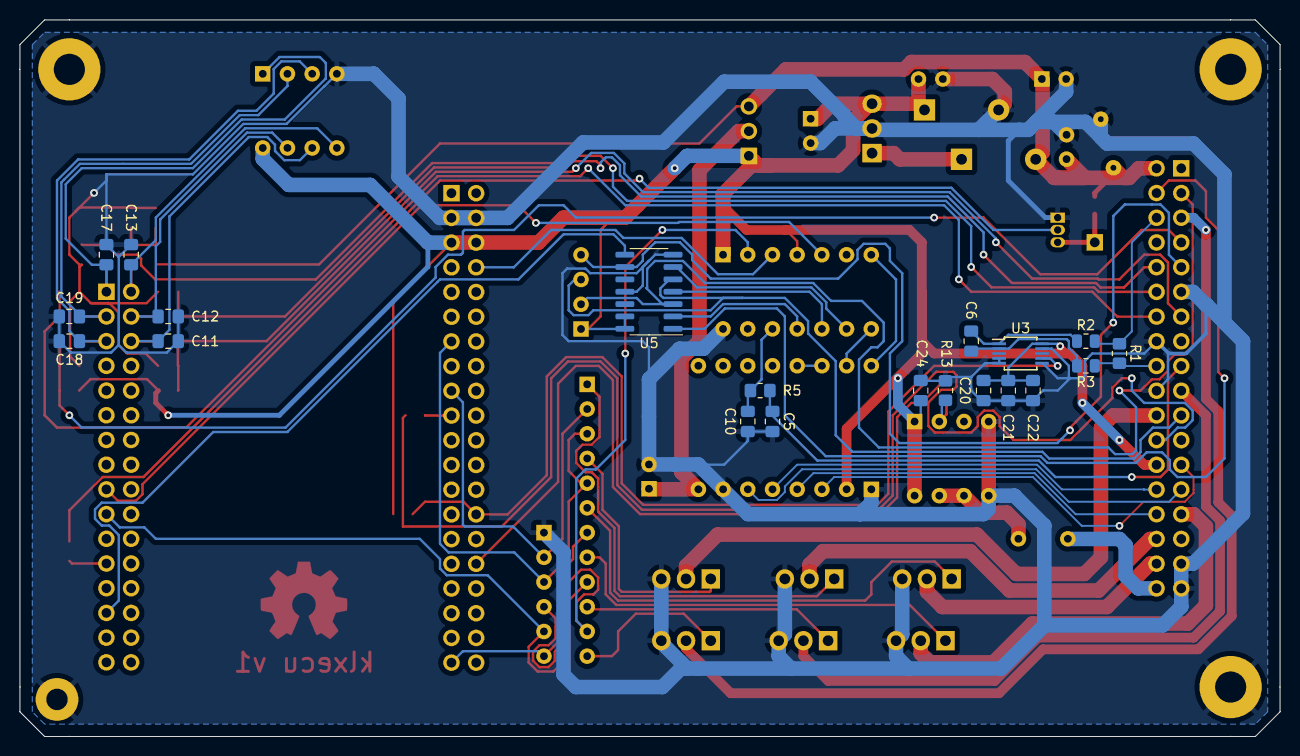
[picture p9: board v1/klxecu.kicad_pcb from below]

Board: 2 copper layers, 129.5 x 73.7 mm, 70 parts (20 on the bottom side), 67 nets.

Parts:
A1: Pololu_Breakout_A4988; Pololu_Breakout-16_15.2x20.3mm
C1: 10uf; CP_Radial_Tantal_D6.0mm_P2.50mm
C2, C3: u1; C_Disc_D3.8mm_W2.6mm_P2.50mm
C4: 47uf; CP_Radial_Tantal_D6.0mm_P2.50mm
C5, C7, C8, C9, C14, C15, C16, C21: 0.1uf; C_0805_2012Metric_Pad1.18x1.45mm_HandSolder
C6: 1nf; C_0805_2012Metric_Pad1.18x1.45mm_HandSolder
C10, C11, C12, C13, C18, C19: 0.22uF; C_0805_2012Metric_Pad1.18x1.45mm_HandSolder
C17: 0.33uF; C_0805_2012Metric_Pad1.18x1.45mm_HandSolder
C20: 10nf; C_0805_2012Metric_Pad1.18x1.45mm_HandSolder
C22, C24: 1uf; C_0805_2012Metric_Pad1.18x1.45mm_HandSolder
C23: 100uf; CP_Radial_D5.0mm_P2.50mm
D1: 1N5818; D_DO-41_SOD81_P7.62mm_Horizontal
D2: 1N5919BG; D_DO-41_SOD81_P7.62mm_Horizontal
IC1: SP721; DIP-8_W7.62mm
J1: Conn_02x20_Odd_Even; PinSocket_2x20_P2.54mm_Vertical
J2: Conn_02x18_Odd_Even; PinHeader_2x18_P2.54mm_Vertical
J3: Conn_02x16_Odd_Even; PinSocket_2x16_P2.54mm_Vertical
J4: Conn_01x01_Male; PinHeader_1x01_P2.54mm_Vertical
JP1: Jumper_3_Open; PinHeader_1x03_P2.54mm_Vertical
Q1: 2N3904; TO-92_Inline
Q2, Q3, Q4, Q5, Q6, Q7: STP62NS04Z; TO-220-3_Vertical
R1: 4.7k; R_0805_2012Metric_Pad1.20x1.40mm_HandSolder
R2, R3, R10: 10k; R_0805_2012Metric
R4, R8: 2.49k; R_0805_2012Metric_Pad1.20x1.40mm_HandSolder
R5, R16, R17, R18, R19, R20, R21: 470; R_0805_2012Metric_Pad1.20x1.40mm_HandSolder
R6: 3.9k; R_0805_2012Metric_Pad1.20x1.40mm_HandSolder
R7, R9, R11, R12, R15: 1k; R_0805_2012Metric_Pad1.20x1.40mm_HandSolder
R13: 100k; R_0805_2012Metric_Pad1.20x1.40mm_HandSolder
R14: 47 2w; R_Axial_DIN0207_L6.3mm_D2.5mm_P5.08mm_Vertical
RN2: 100k; R_Array_SIP6
RN3: 1k; R_Array_SIP12
RN4: 10k; R_Array_SIP4
U1: ERZ-V14D220; RV_Disc_D7mm_W3.4mm_P5mm
U2: LM340T-5.0; TO-220-3_Vertical
U3: MAX9924UAUB+; MSOP-10_3x3mm_P0.5mm
U4: ATtiny84-20P; DIP-14_W7.62mm
U5: 74LS14DR; SOIC-14_3.9x8.7mm_P1.27mm
U6: TC4422AVPA; DIP-8_W7.62mm

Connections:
+5V: A1.2 (VDD), C3.1, C4.1, C20.1, C21.1, C22.1, C24.1, D2.1 (K), IC1.8, J1.5, J1.6, J2.26, JP1.1 (A), R4.1, R8.1, R11.1, RN4.1 (R1.1), U2.3 (VO), U3.10 (VCC), U4.1 (VCC), U4.4 (~RESET/PB3), U5.13, U5.14 (VCC), U6.1 (VDD), U6.8 (VDD)
+12V: C1.1, C2.1, D1.2 (A), J2.2, JP1.3 (B), R6.2, R10.2, U1.1
ARDUINO-A0: C17.1, IC1.1, J3.1, R19.2
ARDUINO-A1: C13.1, IC1.5, J3.2, R18.2
ARDUINO-A2: C19.1, IC1.2, J3.3, R21.2
ARDUINO-A3: C12.1, IC1.7, J3.4, R17.2
ARDUINO-A4: C18.1, IC1.3, J3.5, R20.2
ARDUINO-A5: C11.1, IC1.6, J3.6, R16.2
ARDUINO-D4: J1.13, RN2.3 (R2.2), RN3.3 (R2.1), RN3.5 (R3.1)
ARDUINO-D8: J1.17, RN2.2 (R1.2), RN3.2 (R1.2)
ARDUINO-D19: J1.28, R11.2, U3.7 (COUT)
ARDUINO-D23: J1.32, R12.1
ARDUINO-D30: J1.39, RN2.6 (R5.2), RN3.7 (R4.1)
ARDUINO-D32: J3.17, U4.5 (PB2)
ARDUINO-D34: J3.19, RN2.5 (R4.2), RN3.9 (R5.1)
ARDUINO-D38: J3.23, R9.2
ARDUINO-D42: J3.27, U5.8
ARDUINO-RST: J1.8, U4.3 (XTAL2/PB1)
ATTINY-A1: C10.1, R5.2, U4.12 (PA1)
ATTINY-A2: U4.11 (PA2), U5.2
ATTINY-A3: U4.10 (PA3), U5.4
ATTINY-A4: U4.9 (PA4), U5.6
ATTINY-D10: RN2.4 (R3.2), RN3.11 (R6.1), U4.2 (XTAL1/PB0)
CHECK ENGINE: J2.5, Q5.2 (D)
CKP +: J2.6, R1.1, R2.2
CKP -: J2.18, R1.2, R3.1
CLT: C15.1, J2.7, R8.2, R20.1
CLUTCH SW: J2.24, R15.2
FAN RELAY: J2.29, Q4.2 (D)
FP RELAY: J2.22, Q3.2 (D)
GND: A1.1 (GND), A1.7 (GND), C1.2, C2.2, C3.2, C4.2, C5.2, C7.2, C8.2, C9.2, C10.2, C11.2, C12.2, C13.2, C14.2, C15.2, C16.2, C17.2, C18.2, C19.2, C20.2, C21.2, C22.2, C23.2, C24.2, D2.2 (A), IC1.4, J1.3, J1.4, J2.11, J2.16, J2.20, J2.33, J2.35, Q1.1 (E), Q2.3 (S), Q3.3 (S), Q4.3 (S), Q5.3 (S), Q6.3 (S), Q7.3 (S), R7.1, R13.2, RN2.1 (R1.1), U1.2, U2.2 (GND), U3.4 (BIAS), U3.5 (GND), U3.6 (ZERO_EN), U3.9 (INT_THRS), U4.14 (GND), U5.7 (GND), U5.11, U6.4 (GND), U6.5 (GND)
IAT: C7.1, J2.13, R4.2, R16.1
IGN: J2.36, R14.1
INJECTOR: J2.32, Q2.2 (D)
KICKSTAND SW: J2.21, RN4.3 (R2.2), U5.5
MAP: C14.1, J2.12, R19.1
NEUTRAL SW: J2.3, RN4.2 (R1.2), U5.3
unnamed: A1.8 (VMOT), C23.1, JP1.2 (C)
unnamed: A1.13 (~RESET), A1.14 (~SLEEP)
unnamed: A1.15 (STEP), U4.8 (PA5)
unnamed: A1.16 (DIR), U4.7 (PA6)
unnamed: C6.1, R2.1, U3.1 (IN+)
unnamed: C6.2, R3.2, U3.2 (IN-)
unnamed: C9.1, R6.1, R7.2, R18.1
unnamed: D1.1 (K), U2.1 (VI)
unnamed: J1.19, R15.1
unnamed: J4.1, Q1.3 (C), R10.1
unnamed: Q1.2 (B), R9.1
unnamed: Q2.1 (G), RN3.1 (R1.1)
unnamed: Q3.1 (G), RN3.4 (R2.2)
unnamed: Q4.1 (G), RN3.8 (R4.2)
unnamed: Q5.1 (G), RN3.12 (R6.2)
unnamed: Q6.1 (G), RN3.6 (R3.2)
unnamed: Q7.1 (G), RN3.10 (R5.2)
unnamed: R12.2, R13.1, U6.2 (INPUT)
unnamed: R14.2, U6.6 (OUTPUT), U6.7 (OUTPUT)
O2S +: C16.1, J2.14, R21.1
O2S HEAT +: J2.34, Q6.2 (D)
SELF DIAG: J2.9, RN4.4 (R3.2), U5.9
SUB A +: A1.4 (1A), J2.30
SUB A -: A1.3 (1B), J2.25
SUB B +: A1.5 (2A), J2.28
SUB B -: A1.6 (2B), J2.27
SUB TPS: C5.1, J2.17, R5.1
TEMP WARN: J2.19, Q7.2 (D)
TPS: C8.1, J2.10, R17.1
Vehicle Down: J2.4, U5.1

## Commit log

2022-01-10 Schematic mostly complete, missing control for subthrottle valve
    [klxecu.kicad_sch]
2022-01-10 All sensors and components (minus subthrottle actuator)
    [klxecu.kicad_sch]
2022-01-10 Add jumper to RST -> CHECK ENGINE output
    [klxecu.kicad_sch]
2022-01-11 Change to regular jumper instead of solder jumper
    [klxecu.kicad_sch]
2022-01-11 Added footprints
    [klxecu.kicad_sch]
2022-01-11 begin PCB routing
    [klxecu.kicad_pcb, klxecu.kicad_sch]
2022-01-12 more updates
    [klxecu.kicad_pcb]
2022-01-12 Technically all the nets are connected
    [klxecu.kicad_pcb, klxecu.kicad_sch]
2022-01-13 Misc updates
    - Add pin to handle cluch for launch control
    - re-do PCB from scratch (more things go on the backside this time)
    [klxecu-B_Cu.gbr, klxecu-B_Mask.gbr, klxecu-B_Paste.gbr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]
2022-01-14 Fix up board, add copper fills
    [klxecu.kicad_pcb, klxecu.kicad_sch]
2022-01-14 add gerber files
    [klxecu-B_Cu.gbl, klxecu-B_Cu.gbr, klxecu-B_Mask.gbr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]
2022-01-18 clean up folders
    [klxecu-B_Cu.gbl, klxecu-B_Mask.gbs, klxecu-B_Paste.gbp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]
2022-01-27 Begin v2
    - firmware compatible with the regular speeduino 0.4.4c board (v1 is no2c compatible)
    - added dedicated footprint for the arduino mega pro
    [klxecu.kicad_sch]
2022-01-28 Add footprint for JST WPZ connector
2022-01-28 Change low current transistors to SMT
    [klxecu.kicad_sch]
2022-01-28 add silkscreen outline for VR conditioner module
    [klxecu.kicad_sch]
2022-01-29 fix tach output
    [klxecu.kicad_sch]
2022-01-30 create custom symbol for schmitt trigger & fix label for subthrottle stepper output
    [klxecu.kicad_sch]
2022-01-30 Changed to hierarchy of sheets
    [inputs.kicad_sch, klxecu.kicad_sch, outputs.kicad_sch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]
2022-01-30 Add labels
    [inputs.kicad_sch, klxecu.kicad_sch, sensors.kicad_sch]
2022-01-31 update hierarchy
    [inputs.kicad_sch, outputs.kicad_sch, sensors.kicad_sch]
2022-02-03 Delete ATTiny and associated circuitry
    Control the secondary throttle w/ open loop stepper idle control in the speeduino firmware
    [inputs.kicad_sch, klxecu.kicad_pcb, klxecu.kicad_sch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]
2022-02-03 Reassign check engine light net
    [outputs.kicad_sch]
2022-02-04 V2.1 is done?
    Uses the JST WPZ connector footprint instead of standard
    [klxecu-B_Cu.gbl, klxecu-B_Mask.gbs, klxecu-B_Paste.gbp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]
2022-02-05 Re-add traces for oxygen sensor
    [klxecu.kicad_pcb, klxecu.kicad_sch, sensors.kicad_sch]
2022-02-05 Add control of air switching valve
    Plus a jumper to lock the valve closed
    [klxecu.kicad_pcb, klxecu.kicad_sch, outputs.kicad_sch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]
2022-02-05 add 12v/5v/GND options to cam sensor connector
    [klxecu.kicad_pcb, klxecu.kicad_sch]
2022-02-05 Add reset protection jumper
    [klxecu-B_Cu.gbl, klxecu-B_Mask.gbs, klxecu-B_Paste.gbp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]
2022-02-06 Add V3
    Arduino is on back, a CDI proto area is included
    [inputs.kicad_sch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]
2022-02-09 Reposition components to improve routing and resolve warnings
    [klxecu.kicad_pcb]
2022-02-09 Move o2s resistors to back of board
    [klxecu.kicad_pcb]
2022-02-25 change kill switch circuitry
    [klxecu.kicad_pcb, klxecu.kicad_sch, sensors.kicad_sch]
2022-02-28 V4 -> THT design
    Too many small SMD components in V3
    [inputs.kicad_sch, klxecu.kicad_pcb, klxecu.kicad_sch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]
2022-03-01 V4 potential design
    [klxecu-B_Cu.gbl, klxecu-B_Mask.gbs, klxecu-B_Paste.gbp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]
2022-03-02 Convert to a 2 layer board
    [klxecu.kicad_pcb, sensors.kicad_sch]
2022-03-02 Update gerber files
    [klxecu-B_Cu.gbl, klxecu-B_Mask.gbs, klxecu-B_Paste.gbp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]
2022-03-02 Add zipfile and update board rendering
